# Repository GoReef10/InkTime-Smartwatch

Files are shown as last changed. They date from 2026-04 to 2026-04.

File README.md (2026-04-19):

# InkTime Smartwatch Project

InkTime is an open source startup focused on developing an affordable and customizable smartwatch centered around the nRF52840 SoC and e-ink display technology. This repository contains the full hardware design, including the schematic, PCB layout, and mechanical integration files required for mass production.

## Component Block Diagram
Block Diagram

## Bill of Materials

| Device | Value | Qty | Parts | Product Link | Datasheet Link |
| --- | --- | --: | --- | --- | --- |
| NORDIC_NRF_4_NRF52840_QF | nRF52840-QIAA | 1 | U1 | [JLCPCB](https://jlcpcb.com/partdetail/NordicSemicon-NRF52840_QIAAR/C190794) | [Datasheet](https://infocenter.nordicsemi.com/pdf/nRF52840_PS_v1.9.pdf) |
| RT6160AWSC | RT6160AWSC | 1 | IC9 | [JLCPCB](https://jlcpcb.com/partdetail/RichtekTech-RT6160AWSC/C7065276) | [Datasheet](https://www.mouser.com/datasheet/2/1458/DS6160A_03-3104604.pdf) |
| BQ25180YBGR | BQ25180YBGR | 1 | IC1 | [JLCPCB](https://jlcpcb.com/partdetail/TexasInstruments-BQ25180YBGR/C3682423) | [Datasheet](https://www.ti.com/lit/ds/symlink/bq25180.pdf) |
| ESP32_C6_LIBRARY_MAX17048G+T10 | MAX17048G+T10 | 1 | U3 | [JLCPCB](https://jlcpcb.com/partdetail/MaximIntegrated-MAX17048GT10/C2682616) | [Datasheet](https://www.analog.com/media/en/technical-documentation/data-sheets/MAX17048-MAX17049.pdf) |
| DRV2605YZFR | DRV2605YZFR | 1 | IC2 | [JLCPCB](https://jlcpcb.com/partdetail/TexasInstruments-DRV2605YZFR/C81079) | [Datasheet](https://www.ti.com/lit/ds/symlink/drv2605.pdf) |
| BMA421 | BMA421 | 1 | IC3 | [JLCPCB](https://jlcpcb.com/partdetail/BoschSensortec-BMA421/C5242966) | [Datasheet](https://files.pine64.org/doc/datasheet/pinetime/BST-BMA421-FL000.pdf) |
| DMG2305UX-7 | DMG2305UX-7 | 1 | Q2 | [JLCPCB](https://jlcpcb.com/partdetail/HXYMOSFET-DMG2305UX7/C5261054) | [Datasheet](https://www.diodes.com/assets/Datasheets/DMG2305UX.pdf) |
| ESP32_C6_LIBRARY_6_SI1308EDL-T1-GE3 | SI1308EDL-T1-GE3 | 1 | Q3 | [JLCPCB](https://jlcpcb.com/partdetail/TECHPUBLIC-SI1308EDL/C7603347) | [Datasheet](https://www.vishay.com/docs/63399/si1308edl.pdf) |
| USBLC6-2SC6Y | USBLC6-2SC6Y | 1 | D3 | [JLCPCB](https://jlcpcb.com/partdetail/TECHPUBLIC-USBLC62SC6Y/C5310974) | [Datasheet](https://wmsc.lcsc.com/wmsc/upload/file/pdf/v2/lcsc/2401261525_TECH-PUBLIC-USBLC6-2SC6Y_C5310974.pdf) |
| MBR0530 | MBR0530 | 3 | D2, D4, D5 | [JLCPCB](https://jlcpcb.com/partdetail/4324765-MBR0530_F20000HF/C3757235) | [Datasheet](https://wmsc.lcsc.com/wmsc/upload/file/pdf/v2/lcsc/2205311800_Yangzhou-Yangjie-Electronic-Technology-MBR0530-F2-0000HF_C3757235.pdf) |
| KH-TYPE-C-16P_KH-TYPE-C-16P | KH-TYPE-C-16P | 1 | J4 | [JLCPCB](https://jlcpcb.com/partdetail/KH-TYPE-C-16P/C709357) | [Datasheet](https://wmsc.lcsc.com/wmsc/upload/file/pdf/v2/lcsc/2204251630_SHENZHEN-KINGHELM-Elec-KH-TYPE-C-16P_C709357.pdf) |
| 5034802400 | 503480-2400 | 1 | J1 | [JLCPCB](https://jlcpcb.com/partdetail/MOLEX-5034802400/C122434) | [Datasheet](https://www.mouser.com/datasheet/2/276/2/5034802400_FFC_FPC_CONNECTORS-1112921.pdf) |
| EVP-AKE31A | EVP-AKE31A | 3 | SW_DN, SW_ENT, SW_UP | [JLCPCB](https://jlcpcb.com/partdetail/PANASONIC-EVPAKE31A/C569760) | [Datasheet](https://www.lcsc.com/datasheet/C569760.pdf) |
| 2450AT18B100E_2450AT18B100E | 2450AT18B100E | 1 | ANT1 | [JLCPCB](https://jlcpcb.com/partdetail/JohansonTechnology-2450AT18B100/C2836414) | [Datasheet](https://www.johansontechnology.com/datasheets/antennas/2450AT18B100.pdf) |
| NX2016SA-32MHZ-STD-CZS-5 | 32 MHz | 1 | X1 | [JLCPCB](https://jlcpcb.com/partdetail/NDK-NX2016SA_32MHZ_STD_CZS5/C843260) | [Datasheet](https://www.lcsc.com/datasheet/C843260.pdf) |
| NORDIC_NRF_1_XTAL_32KHZ | 32.768 kHz | 1 | X2 | [JLCPCB](https://jlcpcb.com/partdetail/NDK-NX3215SA_32_768K_STD_MUA9/C519280) | [Datasheet](https://www.ndk.com/images/products/crystal/resonator/NX3215SA_e.pdf) |
| MLP2016SR47MT0S1_FTC252012SR47MBCA | FTC252012SR47MBCA | 1 | L7 | [JLCPCB](https://jlcpcb.com/partdetail/6763488-FTC252012SR47MBCA/C5832368) | [Datasheet](https://wmsc.lcsc.com/wmsc/upload/file/pdf/v2/lcsc/2311271530_TDK-FTC252012SR47MBCA_C5832368.pdf) |
| VHF060303H3N9ST | 3.9 nH | 1 | L1 | [JLCPCB](https://jlcpcb.com/partdetail/153834-VHF060303H3N9ST/C142503) | [Datasheet](https://www.lcsc.com/datasheet/C142503.pdf) |
| MLK0603L15NJT000 | 15 nH | 1 | L3 | [JLCPCB](https://jlcpcb.com/partdetail/TDK-MLK0603L15NJT000/C6990407) | [Datasheet](https://www.lcsc.com/datasheet/C6990407.pdf) |
| RNCF0201DTC3K30 | 3.3 kΩ | 2 | R17, R18 | [JLCPCB](https://jlcpcb.com/partdetail/SEI_Stackpole_Elec-RNCF0201DTC3K30/C2487997) | [Datasheet](https://www.lcsc.com/datasheet/C2487997.pdf) |
| RC0201FR-075K1L | 5.1 kΩ | 2 | R1_USB, R2_USB | [JLCPCB](https://jlcpcb.com/partdetail/YAGEO-RC0201FR075K1L/C274341) | [Datasheet](https://www.lcsc.com/datasheet/C274341.pdf) |
| RC0201FR-1310KL | 10 kΩ | 6 | R2_EP_DR, R5, R7, R8, R9, R_PWR_EPD | [JLCPCB](https://jlcpcb.com/partdetail/YAGEO-RC0201FR1310KL/C6373588) | [Datasheet](https://www.lcsc.com/datasheet/C6373588.pdf) |
| 0201WMF220KTCE | 2.2 Ω | 1 | R_TYPE_SEL | [JLCPCB](https://jlcpcb.com/partdetail/244650-0201WMF220KTCE/C247442) | [Datasheet](https://www.lcsc.com/datasheet/C247442.pdf) |
| 0201WMJ0000TCE | 0 Ω | 3 | R2, R3, R4 | [JLCPCB](https://jlcpcb.com/partdetail/25793-0201WMJ0000TCE/C25050) | [Datasheet](https://www.lcsc.com/datasheet/C25050.pdf) |
| MA0201XF821K250 | 820 pF | 1 | C9 | [JLCPCB](https://jlcpcb.com/partdetail/Meritek-MA0201XF821K250/C3842403) | [Datasheet](https://www.lcsc.com/datasheet/C3842403.pdf) |
| GRM0335C1E1R0CA01J | 1 pF | 2 | C3, C4 | [JLCPCB](https://jlcpcb.com/partdetail/2274979-GRM0335C1E1R0CA01J/C2182912) | [Datasheet](https://www.lcsc.com/datasheet/C2182912.pdf) |
| 0201N120J250CT | 12 pF | 4 | C1, C2, C17, C18 | [JLCPCB](https://jlcpcb.com/partdetail/Walsin_TechCorp-0201N120J250CT/C424835) | [Datasheet](https://www.lcsc.com/datasheet/C424835.pdf) |
| 0201N101F160CT | 100 pF | 1 | C11 | [JLCPCB](https://jlcpcb.com/partdetail/Walsin_TechCorp-0201N101F160CT/C3847857) | [Datasheet](https://www.lcsc.com/datasheet/C3847857.pdf) |
| C0201X5R473K160NTA | 47 nF | 1 | C16 | [JLCPCB](https://jlcpcb.com/partdetail/126083-C0201X5R473K160NTA/C124806) | [Datasheet](https://www.lcsc.com/datasheet/C124806.pdf) |
| AC0201KRX6S6BB104 | 100 nF | 9 | C5, C7, C8, C12, C19, C23, C27, C34, C42 | [JLCPCB](https://jlcpcb.com/partdetail/YAGEO-AC0201KRX6S6BB104/C3855913) | [Datasheet](https://www.lcsc.com/datasheet/C3855913.pdf) |
| CL05A105KP5NNNC | 1 uF | 1 | C15 | [JLCPCB](https://jlcpcb.com/partdetail/C14445) | [Datasheet](https://www.lcsc.com/datasheet/C14445.pdf) |
| GRM155R61H105KE05D | 1 uF / 50V | 9 | EPD_C1, EPD_C2, EPD_C6, EPD_C7, EPD_C8, EPD_C9, EPD_C10, EPD_C11, EPD_C12 | [JLCPCB](https://jlcpcb.com/partdetail/1609005-GRM155R61H105KE05D/C1518208) | [Datasheet](https://www.lcsc.com/datasheet/C1518208.pdf) |
| GRM155R61A475KEAAD | 4.7 uF | 5 | C6, C14, C20, C21, C43 | [JLCPCB](https://jlcpcb.com/partdetail/MurataElectronics-GRM155R61A475KEAAD/C77004) | [Datasheet](https://www.lcsc.com/datasheet/C77004.pdf) |
| C0402X5R475M250NT | 4.7 uF / 25V | 1 | C2-EP-DR | [JLCPCB](https://jlcpcb.com/partdetail/SANYEAR-C0402X5R475M250NT/C2911388) | [Datasheet](https://www.lcsc.com/datasheet/C2911388.pdf) |
| 0402X106M100CT | 10 uF | 2 | C24, C39 | [JLCPCB](https://jlcpcb.com/partdetail/Walsin_TechCorp-0402X106M100CT/C2992625) | [Datasheet](https://www.lcsc.com/datasheet/C2992625.pdf) |
| CL05A226MQ6ZUN8 | 22 uF | 2 | C25, C33 | [JLCPCB](https://jlcpcb.com/partdetail/2889851-CL05A226MQ6ZUN8/C2762589) | [Datasheet](https://www.lcsc.com/datasheet/C2762589.pdf) |

## Hardware Description

### Microcontroller - nRF52840 (Nordic Semiconductor)

The core of InkTime is the **nRF52840**. It manages all peripherals and runs the main firmware:

### Power System

- **LiPo Charger - BQ25180YBGR :** Single-cell Li-Ion/LiPo charger connected via **I2C**, handles charge current control and power path management.
- **DC/DC Buck-Boost - RT6160AWSC:** Provides the regulated **3.3 V rail** (VREG/3V3) from the battery, using a 10 uH inductor. Supplies the MCU and most peripherals.
- **Fuel Gauge - MAX17048G+T10:** Monitors battery state-of-charge via **I2C**, provides a `ALERT` line to the MCU for low-battery interrupts.

### E-Paper Display

The display connects through a 24-pin FPC connector (J1). The drive circuit uses:
- A boost converter to generate the higher voltages required by e-paper panels (PREVGH/PREVGL rails).
- Communication with the MCU via SPI (MOSI, SCK, CS, DC, RST, BUSY lines).

E-paper was chosen for its near-zero power draw when the display is static - only consuming power during refresh.

### IMU - BMA421

A 3-axis accelerometer connected via I2C, with two interrupt lines (`INT1`, `INT2`) wired to the MCU for step counting, wrist-tilt detection, and activity recognition without polling.

### Haptic Driver - DRV2605YZFR

Controls a vibration motor/LRA actuator. Connected via **I2C**, with an enable line (`HAPTIC_EN`) from the MCU. Supports waveform libraries for rich haptic feedback patterns.

### USB - KH-TYPE-C-16P + USBLC6-2SC6Y

Full-speed USB Type-C connector for charging and data. The USBLC6-2SC6Y provides ESD protection on D+/D− lines. CC1/CC2 resistors (5.1 kΩ) handle cable orientation detection. VBUS is routed to the LiPo charger.

### Buttons

Three tactile buttons (UP, DOWN, ENTER) with pull-up resistors, directly connected to GPIO pins.

### Debug Interface - TC2030-IDC (Tag-Connect)

A 6-pin **SWD** debug/programming header (SWDCLK, SWDIO, RESET, SWO, 3.3V, GND) for firmware flashing and debugging, with test points exposed for each signal.

## nRF52840 Pin Assignment - InkTime v5

### SPI - E-Paper Display
| Pin | Function | Why |
|-----|---|-----|
| P0.08 | MOSI | SPI data out to EPD controller |
| P0.11 | SCK | SPI clock |
| P0.13 | EPD_CS | Chip select - activates the display |
| P0.14 | EPD_DC | Data/Command toggle for EPD protocol |
| P1.01 | EPD_RST | Hardware reset of the display controller |
| P1.02 | EPD_BUSY | Polled input - MCU waits for display to finish refreshing |

### I2C - Shared Bus (BQ25180, MAX17048, BMA421, DRV2605)
| Pin | Function | Why |
|-----|---|-----|
| P0.26 | SCL | I2C clock, shared by all 4 peripherals |
| P0.27 | SDA | I2C data, shared by all 4 peripherals |

### Interrupts & Control
| Pin | Function | Why |
|-----|---|-----|
| P0.04 | PMIC_INT | BQ25180 interrupt - charge events (fault, complete, etc.) |
| P1.09 | ALERT | MAX17048 interrupt - low battery or 1% SoC change |
| P0.25 | IMU_INT1 | BMA421 primary interrupt - step count, wakeup-on-motion |
| P0.24 | IMU_INT2 | BMA421 secondary interrupt - activity recognition events |
| P1.01 | HAPTIC_EN | Enables DRV2605 and triggers haptic waveform playback |

### Buttons
| Pin | Function | Why |
|-----|---|-----|
| P0.29 | SW_UP | Up button - GPIOTE falling-edge interrupt, also wakes MCU from sleep |
| P0.30 | SW_DN | Down button - same as above |
| P0.31 | SW_ENT | Enter button - same as above |

### USB
| Pin | Function | Why |
|-----|---|-----|
| D+ | USB D+ | Native USB 2.0 FS controller - firmware updates, serial debug |
| D− | USB D− | Paired with D+ |
| VBUS | USB power detect | MCU detects cable insertion to enable charging path |

### Crystal Oscillators
| Pin | Function | Why |
|-----|---|-----|
| XL1 / XL2 | 32.768 kHz XTAL | Low-frequency RTC clock - timekeeping during deep sleep |
| XC1 / XC2 | 32 MHz XTAL | Main system clock for CPU and radio |

### SWD Debug
| Pin | Function | Why |
|-----|---|-----|
| SWDCLK | SWD clock | Firmware flashing and live debugging via Tag-Connect |
| SWDIO | SWD data | Bidirectional debug data |
| P1.00 | SWO | Serial Wire Output - trace/printf during development |
| P0.18 | RESET | Hardware reset, also accessible on debug header |

### RF
| Pin | Function | Why |
|-----|---|-----|
| ANT | 2.4 GHz antenna | Connected via LC matching network to the onboard ceramic antenna |
| VSS_PA | PA ground | Dedicated quiet ground for the RF power amplifier |

## Design Log

### Silkscreen
Silkscreen line width was set to **0.9 mm**, reduced to **0.8 mm** in areas where overlap with component courtyard or pad holes would otherwise occur. While the standard recommendation is 1 mm, 0.9 mm remains legible after fabrication. To reduce visual clutter, silkscreen labels were kept only for functionally important components (ICs, connectors, test points) - passive components such as resistors and capacitors were left unlabeled.

### Test Points
All test points (SWD signals, power rails, I2C lines) were placed close to the board edge to allow easy probing during bring-up and testing without needing to reach into the center of the board.

### Antenna Placement
The BLE antenna (2450AT18B100E) was placed at the edge of the PCB, away from other components and copper fills, to minimize RF interference and avoid detuning the antenna due to nearby conductors - a standard requirement for 2.4 GHz PCB antennas.

### Trace Width & Clearance
Power traces were routed at 0.3 mm as per design requirements. In a small number of cases, traces were temporarily narrowed immediately at component pins due to clearance constraints, then returned to 0.3 mm as soon as space allowed. This was done only where unavoidable and over very short distances, keeping the resistive impact negligible.

### 2-Layer Stackup
A 2-layer board (top + bottom copper) was chosen deliberately as the design complexity is manageable within 2 layers, so the added cost of additional layers would bring no practical benefit.

Power traces were routed on the top layer. The only exception is a short segment of the **3V3 trace** which briefly routes through the bottom layer through 3 vias, due to a localized routing constraint. This was kept to an absolute minimum, which is particularly important for noisy nets like the e-paper boost converter output.

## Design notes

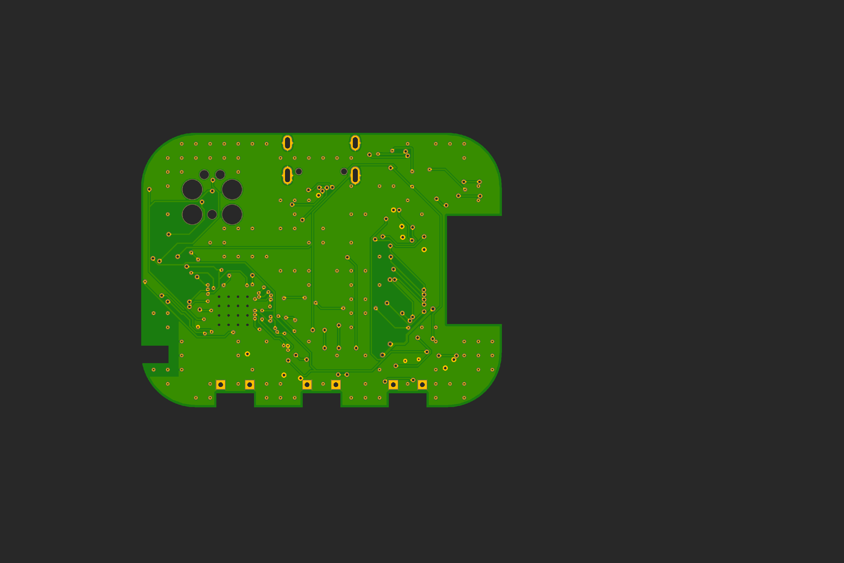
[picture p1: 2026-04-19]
Images/PCB Bottom.png

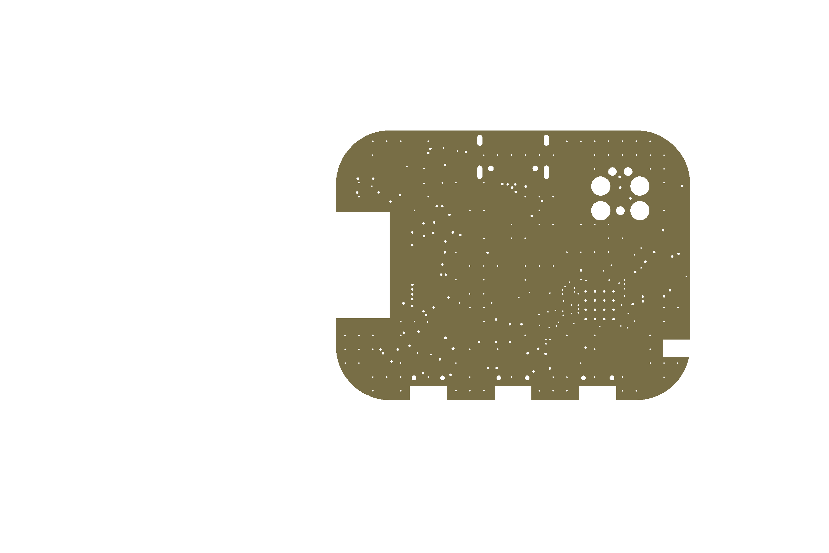
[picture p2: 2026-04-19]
Images/PCB Drills.png

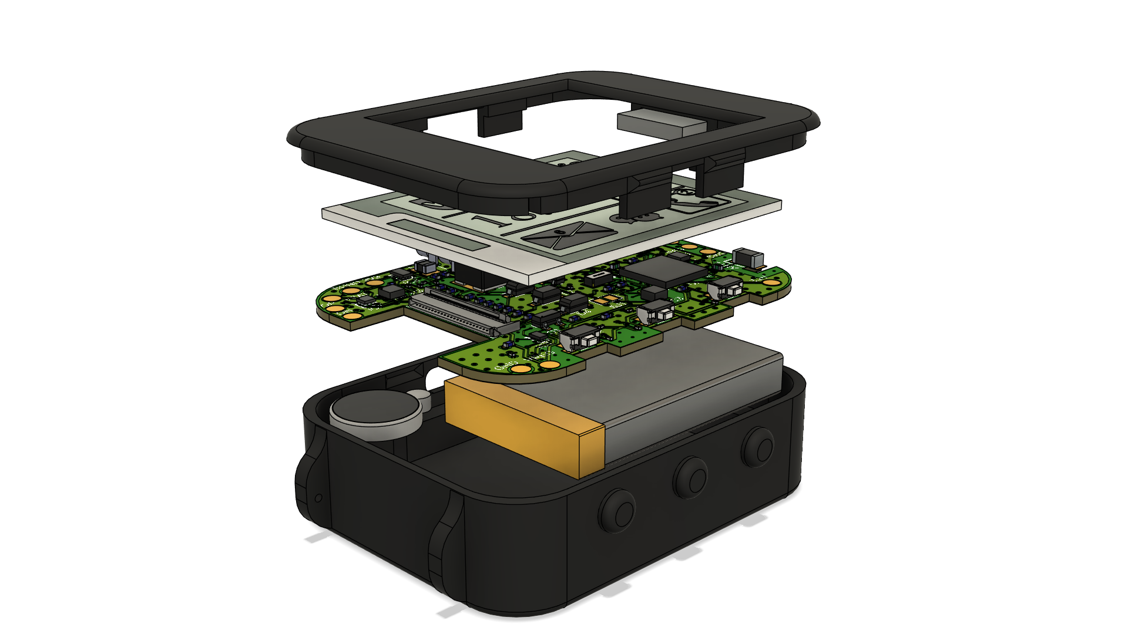
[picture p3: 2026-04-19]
Images/Exploded View.png

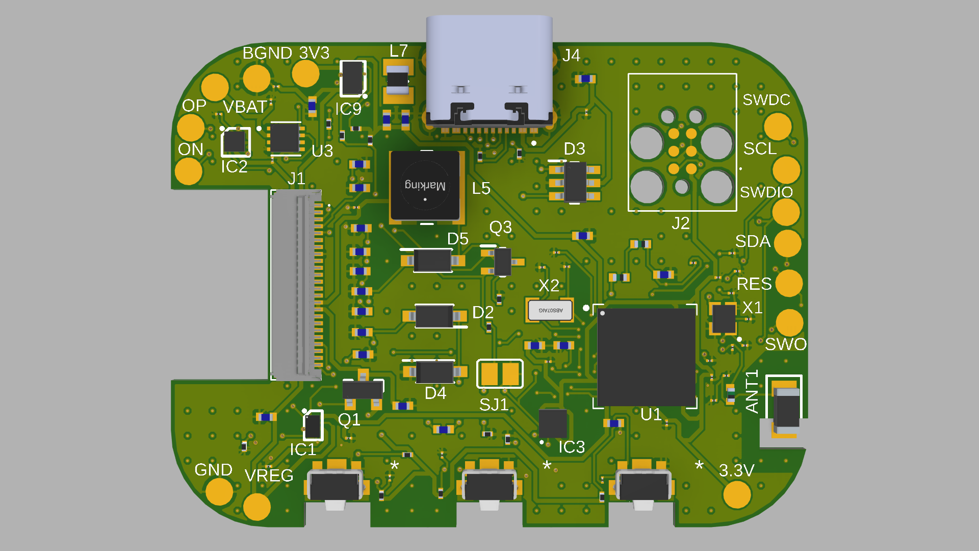
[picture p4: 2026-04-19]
Images/PCB Top View Render.png

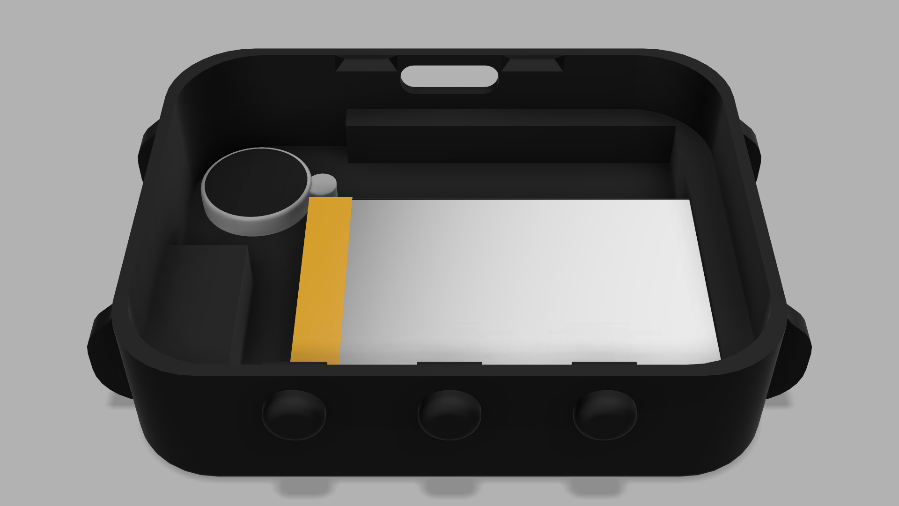
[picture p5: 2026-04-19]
Images/Inside Case.png

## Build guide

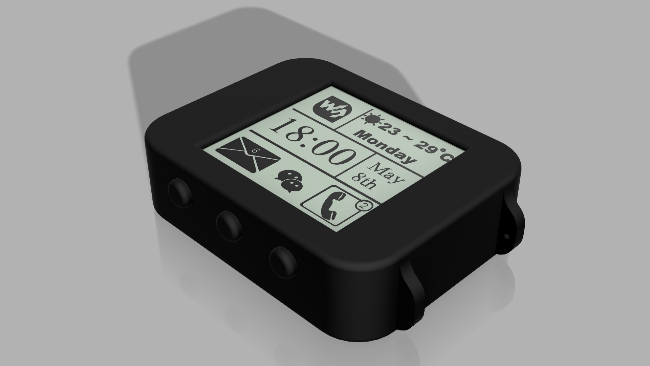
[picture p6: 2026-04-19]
Images/Assembled.png

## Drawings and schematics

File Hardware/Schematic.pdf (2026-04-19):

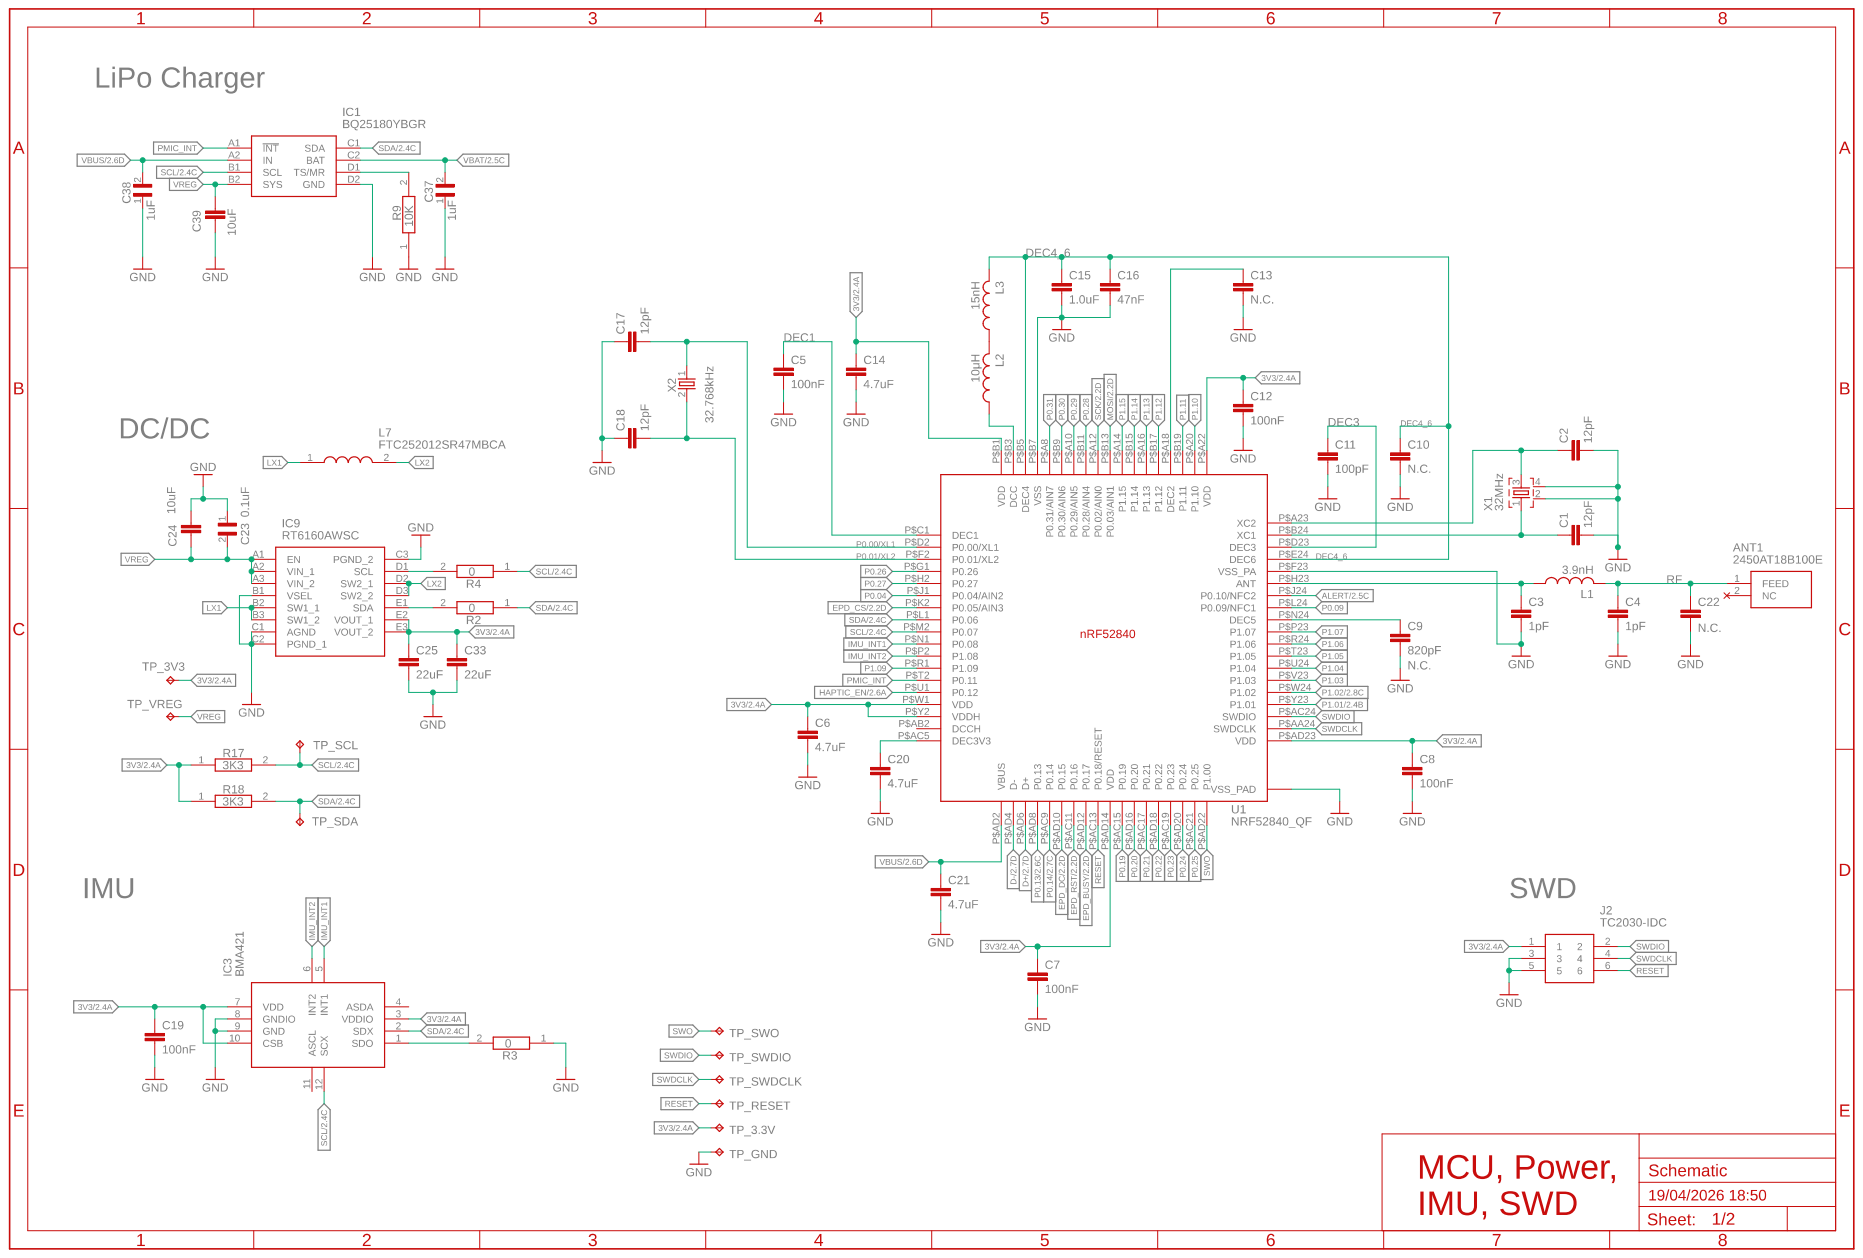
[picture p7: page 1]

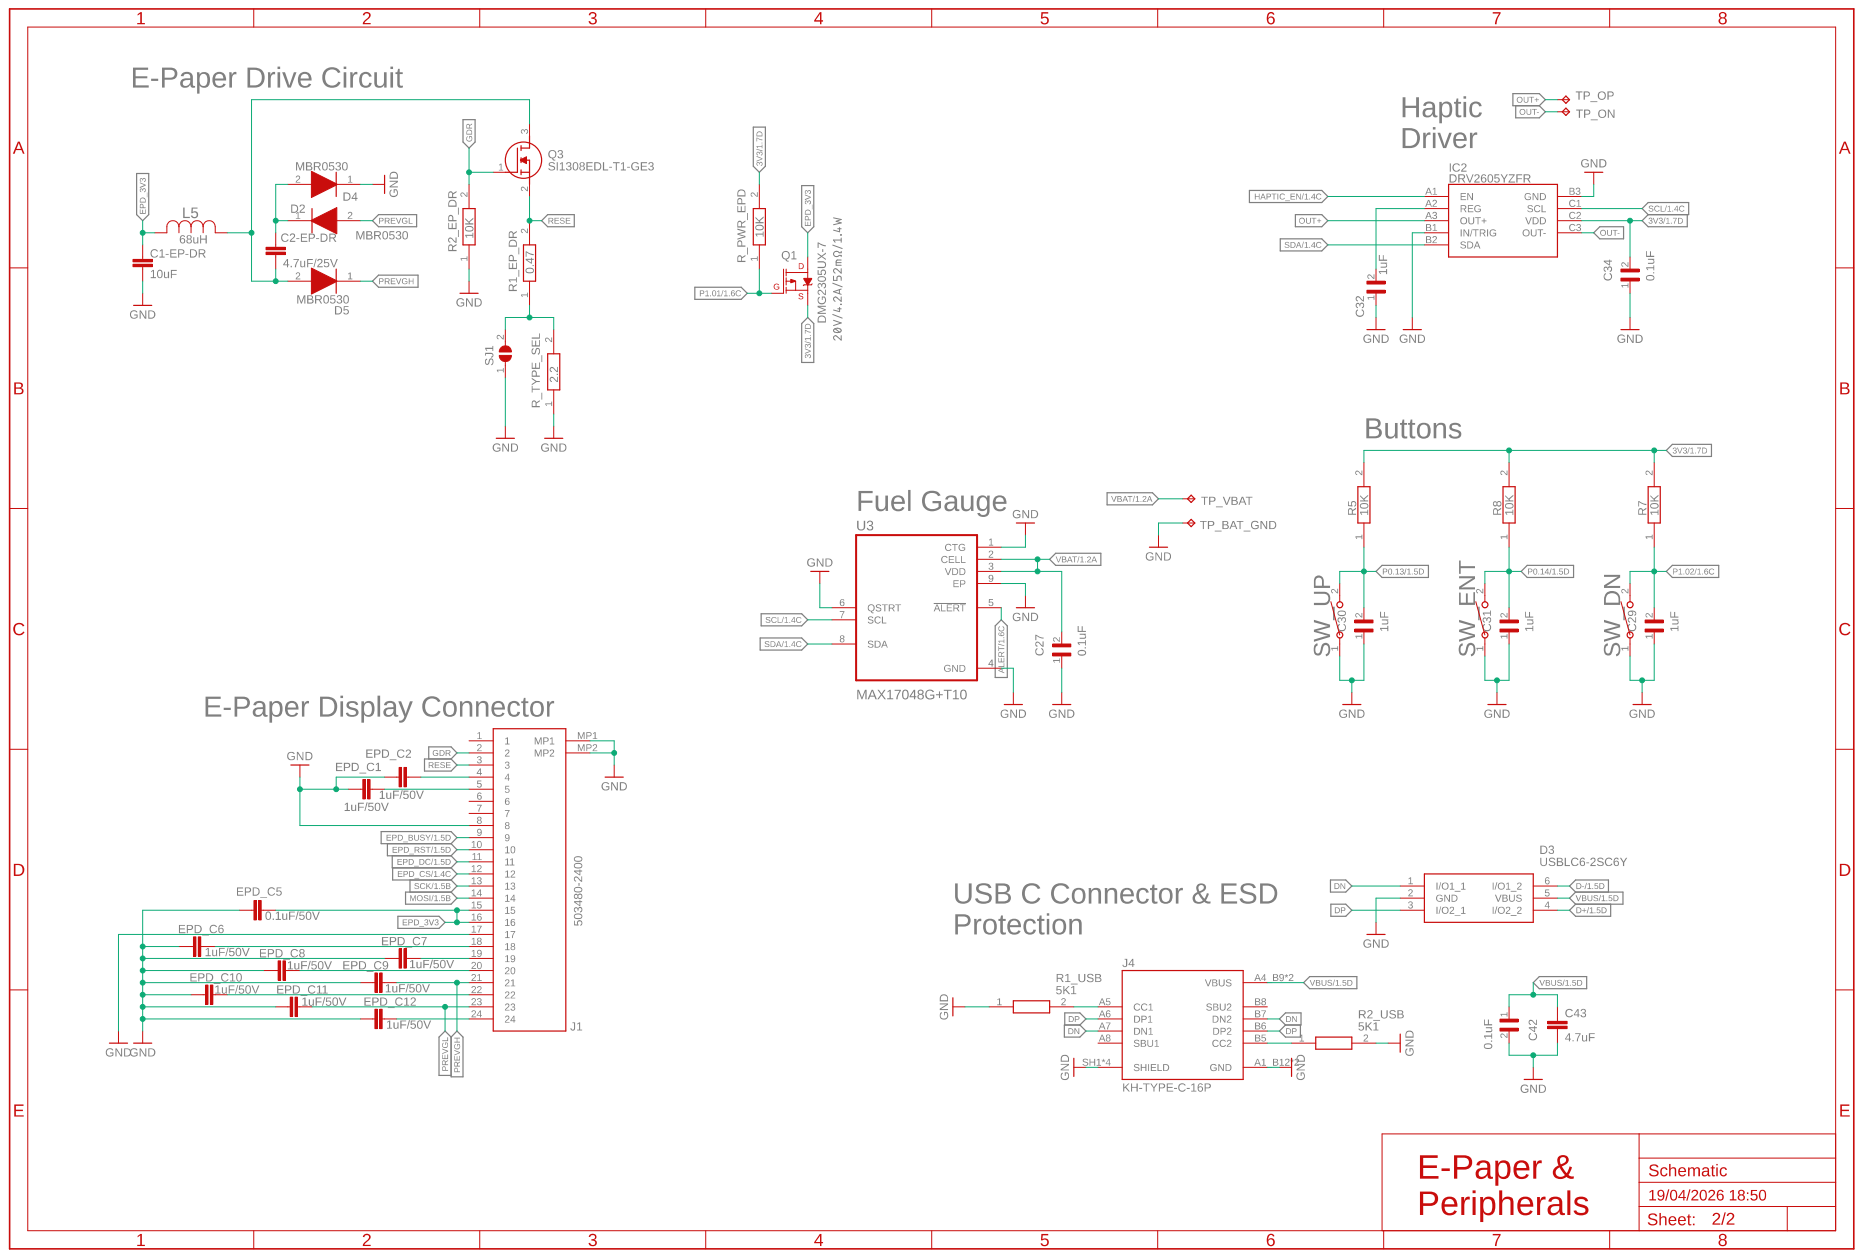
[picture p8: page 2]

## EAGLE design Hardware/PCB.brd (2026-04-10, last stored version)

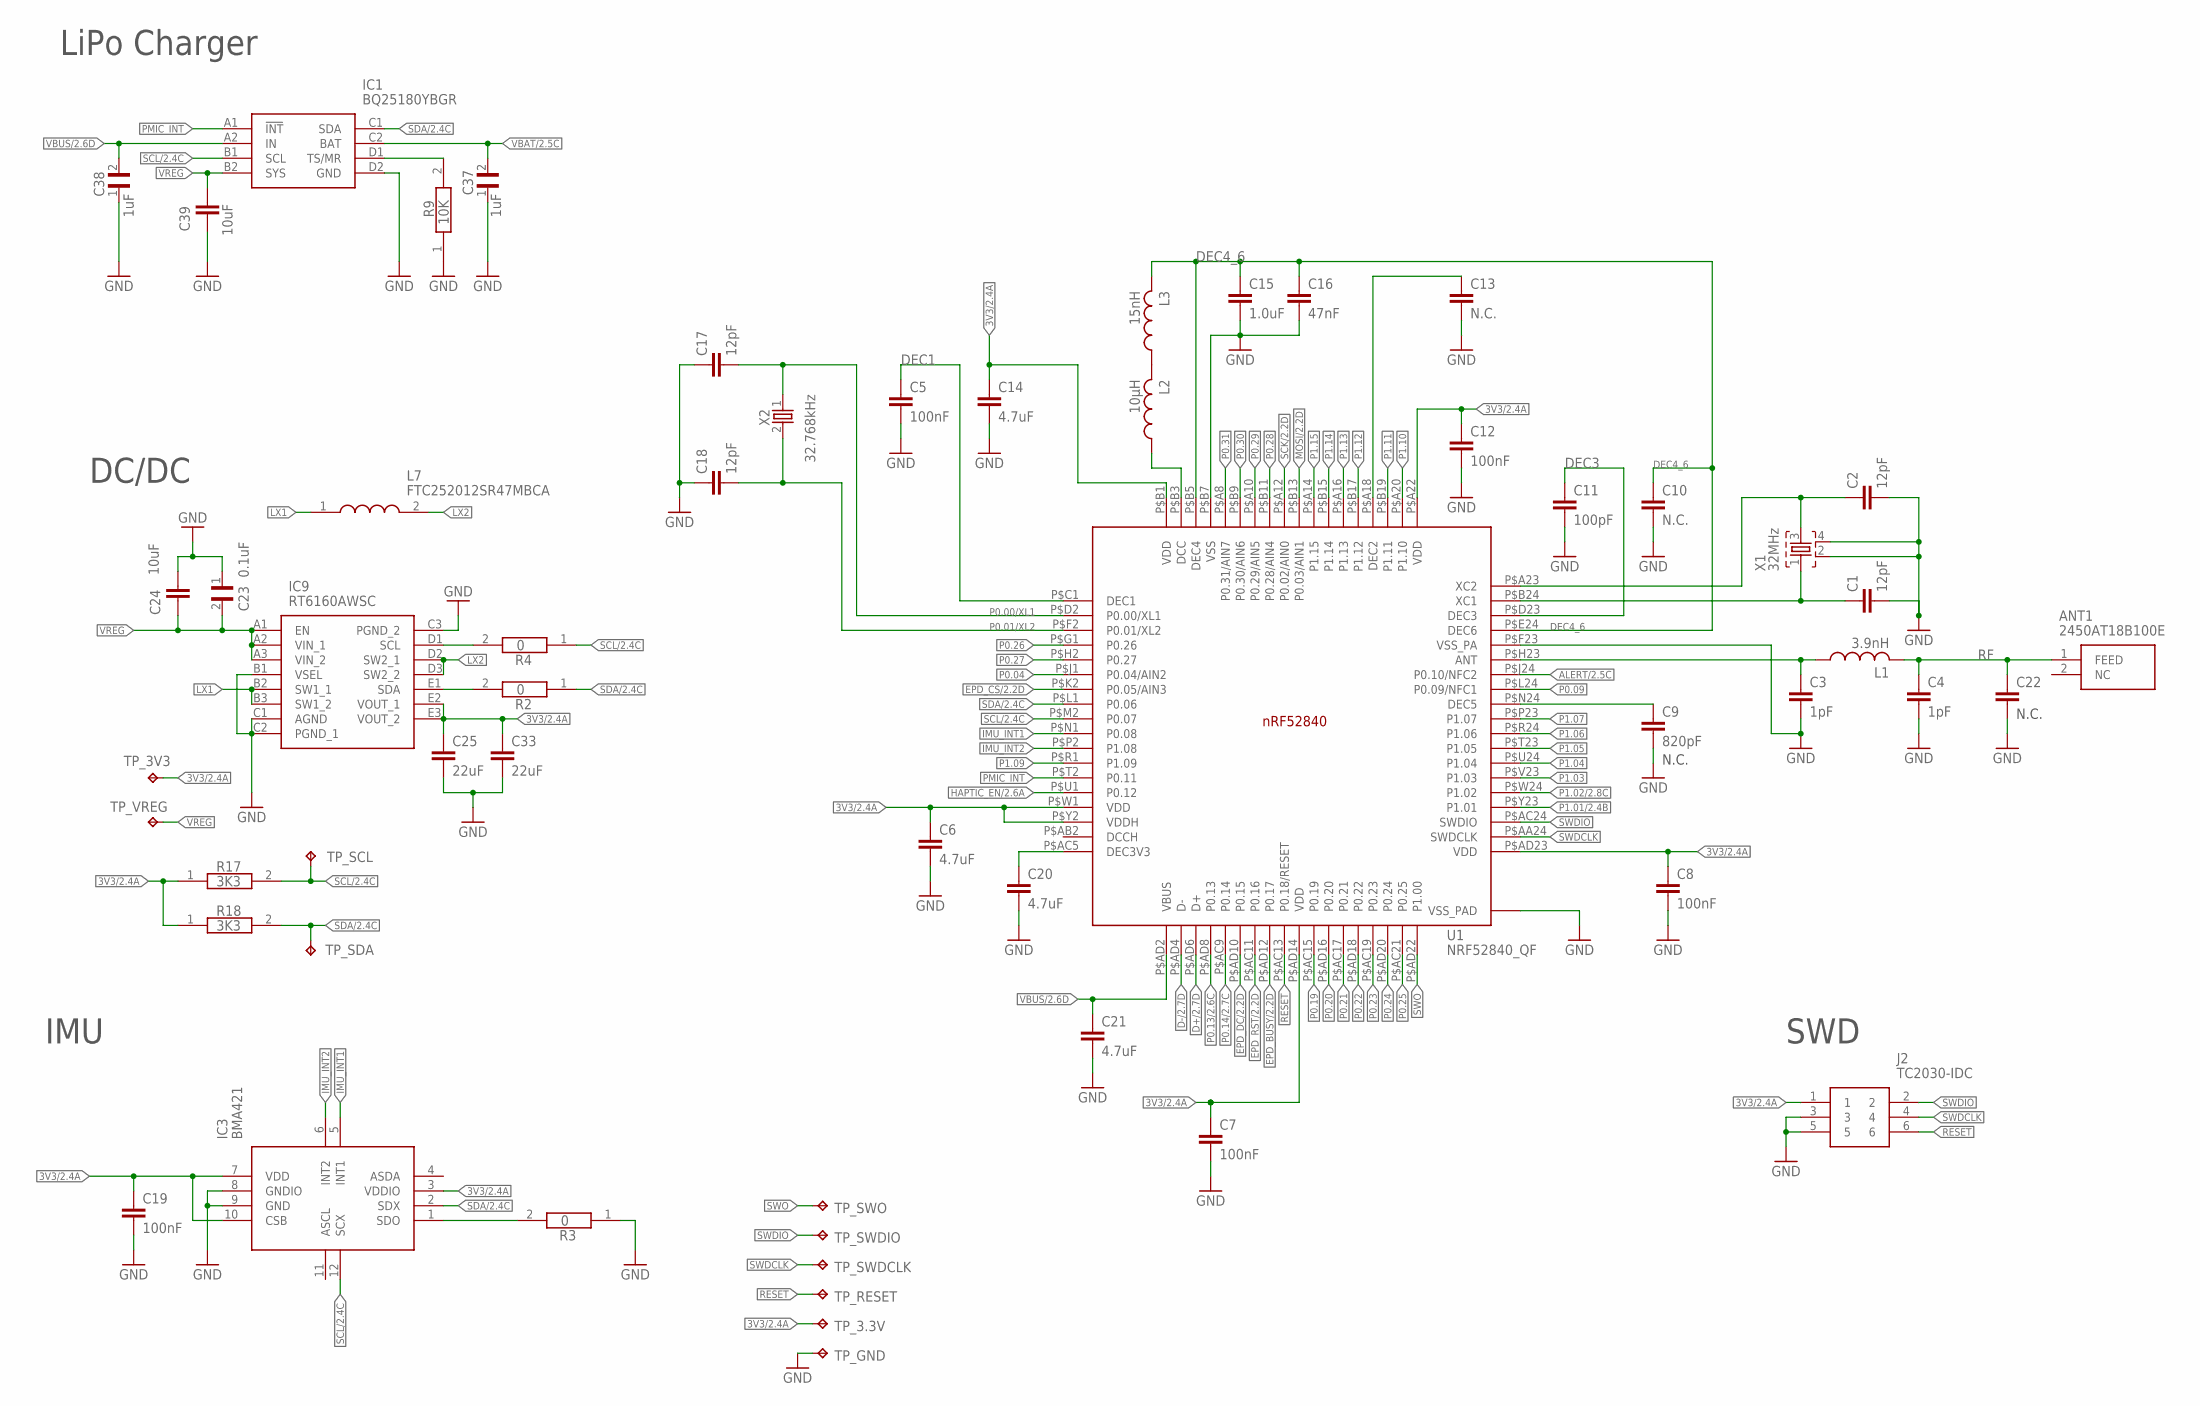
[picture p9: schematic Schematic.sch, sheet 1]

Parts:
ANT1: 2450AT18B100E; 2450AT18B100E_ANTC3216X140N
C1, C2, C17, C18: 12pF; NORDIC_NRF_3_RESC0201_L
C3, C4: 1pF; NORDIC_NRF_3_RESC0201_L
C5, C7, C8, C12, C19: 100nF; NORDIC_NRF_3_RESC0201_L
C6, C14, C20, C21: 4.7uF; NORDIC_NRF_3_RESC0402_L
C9: 820pF; NORDIC_NRF_3_RESC0201_L
C10, C13, C22: N.C.; NORDIC_NRF_3_RESC0201_L
C11: 100pF; NORDIC_NRF_3_RESC0201_L
C15: 1.0uF; NORDIC_NRF_3_RESC0402_L
C16: 47nF; NORDIC_NRF_3_RESC0201_L
C23: 0.1uF; GRM011R60J152KE01L_1_0201
C24, C39: 10uF; NORDIC_NRF_3_RESC0402_L
C25, C33: 22uF; NORDIC_NRF_3_RESC0402_L
C37, C38: 1uF; GRM011R60J152KE01L_1_0201
IC1: BQ25180YBGR; BQ25180YBGR_BGA8C40P2X4_100X155X50
IC3: BMA421; BMA423_BMA423
IC9: RT6160AWSC; RT6160AWSC_BGA15C40P3X5_140X230X60
J2: TC2030-IDC; TC2030-IDC_TC2030IDC
L1: 3.9nH; NORDIC_NRF_2_RESC0402_L
L2: 10μH; NORDIC_NRF_2_RESC0402_L
L3: 15nH; NORDIC_NRF_2_RESC0402_L
L7: FTC252012SR47MBCA; MLP2016SR47MT0S1_INDC2016X100N
R2, R3, R4: 0; ERA-1AEB3401C_0201
R9: 10K; ERA-1AEB3401C_0201
R17, R18: 3K3; ERA-1AEB3401C_0201
TP_3.3V, TP_3V3: HECTOR_WATCH_1_TPTP20R; HECTOR_WATCH_1_TP20R
TP_GND: HECTOR_WATCH_1_TPTP20R; HECTOR_WATCH_1_TP20R
TP_RESET: HECTOR_WATCH_1_TPTP20R; HECTOR_WATCH_1_TP20R
TP_SCL: HECTOR_WATCH_1_TPTP20R; HECTOR_WATCH_1_TP20R
TP_SDA: HECTOR_WATCH_1_TPTP20R; HECTOR_WATCH_1_TP20R
TP_SWDCLK: HECTOR_WATCH_1_TPTP20R; HECTOR_WATCH_1_TP20R
TP_SWDIO: HECTOR_WATCH_1_TPTP20R; HECTOR_WATCH_1_TP20R
TP_SWO: HECTOR_WATCH_1_TPTP20R; HECTOR_WATCH_1_TP20R
TP_VREG: HECTOR_WATCH_1_TPTP20R; HECTOR_WATCH_1_TP20R
U1: NRF52840_QF; NORDIC_NRF_4_AQFN50P700X700X85_HS-74N
X1: 32MHz; NORDIC_NRF_BT-XTAL_2016_N
X2: 32.768kHz; NORDIC_NRF_1_XTAL_3215_N

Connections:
3V3/2.4A: C6.1, C7.1, C8.1, C12.1, C14.1, C19.1, C25.1, C33.1, IC3.3 (VDDIO), IC3.7 (VDD), IC3.10 (CSB), IC9.E2 (VOUT_1), IC9.E3 (VOUT_2), J2.1, R17.1, R18.1, TP_3.3V.TP, TP_3V3.TP, U1.P$A22 (VDD), U1.P$AD14 (VDD), U1.P$AD23 (VDD), U1.P$B1 (VDD), U1.P$W1 (VDD), U1.P$Y2 (VDDH)
ALERT/2.5C: U1.P$J24 (P0.10/NFC2)
D+/2.7D: U1.P$AD6 (D+)
D-/2.7D: U1.P$AD4 (D-)
DEC1: C5.1, U1.P$C1 (DEC1)
DEC3: C11.1, U1.P$D23 (DEC3)
DEC4_6: C10.1, C15.1, C16.1, L3.2, U1.P$B5 (DEC4), U1.P$E24 (DEC6)
EPD_BUSY/2.2D: U1.P$AD12 (P0.17)
EPD_CS/2.2D: U1.P$K2 (P0.05/AIN3)
EPD_DC/2.2D: U1.P$AD10 (P0.15)
EPD_RST/2.2D: U1.P$AC11 (P0.16)
GND: C1.2, C2.2, C3.2, C4.2, C5.2, C6.2, C7.2, C8.2, C9.2, C10.2, C11.2, C12.2, C13.2, C14.2, C15.2, C16.2, C17.1, C18.1, C19.2, C20.2, C21.2, C22.2, C23.1, C24.1, C25.2, C33.2, C37.1, C38.1, C39.2, IC1.D2 (GND), IC3.8 (GNDIO), IC3.9 (GND), IC9.B1 (VSEL), IC9.C1 (AGND), IC9.C2 (PGND_1), IC9.C3 (PGND_2), J2.3, J2.5, R3.1, R9.1, TP_GND.TP, U1.P$74 (VSS_PAD), U1.P$75 (VSS_PAD), U1.P$76 (VSS_PAD), U1.P$77 (VSS_PAD), U1.P$78 (VSS_PAD), U1.P$79 (VSS_PAD), U1.P$80 (VSS_PAD), U1.P$81 (VSS_PAD), U1.P$82 (VSS_PAD), U1.P$83 (VSS_PAD), U1.P$84 (VSS_PAD), U1.P$85 (VSS_PAD), U1.P$86 (VSS_PAD), U1.P$87 (VSS_PAD), U1.P$88 (VSS_PAD), U1.P$89 (VSS_PAD), U1.P$90 (VSS_PAD), U1.P$B7 (VSS), U1.P$F23 (VSS_PA), X1.2, X1.4; also elsewhere on the board
HAPTIC_EN/2.6A: U1.P$U1 (P0.12)
IMU_INT1: IC3.5 (INT1), U1.P$N1 (P0.08)
IMU_INT2: IC3.6 (INT2), U1.P$P2 (P1.08)
LX1: IC9.B2 (SW1_1), IC9.B3 (SW1_2), L7.1
LX2: IC9.D2 (SW2_1), IC9.D3 (SW2_2), L7.2
MOSI/2.2D: U1.P$B13 (P0.03/AIN1)
unnamed: C20.1, U1.P$AC5 (DEC3V3)
unnamed: L2.2, L3.1
unnamed: L2.1, U1.P$B3 (DCC)
unnamed: C1.1, U1.P$B24 (XC1), X1.1
unnamed: C2.1, U1.P$A23 (XC2), X1.3
unnamed: IC9.E1 (SDA), R2.2
unnamed: IC9.D1 (SCL), R4.2
unnamed: IC1.D1 (TS/MR), R9.2
unnamed: C13.1, U1.P$A18 (DEC2)
unnamed: C9.1, U1.P$N24 (DEC5)
unnamed: IC3.1 (SDO), R3.2
unnamed: C3.1, L1.1, U1.P$H23 (ANT)
P0.00/XL1: C17.2, U1.P$D2 (P0.00/XL1), X2.1
P0.01/XL2: C18.2, U1.P$F2 (P0.01/XL2), X2.2
P0.04: U1.P$J1 (P0.04/AIN2)
P0.09: U1.P$L24 (P0.09/NFC1)
P0.13/2.6C: U1.P$AD8 (P0.13)
P0.14/2.7C: U1.P$AC9 (P0.14)
P0.19: U1.P$AC15 (P0.19)
P0.20: U1.P$AD16 (P0.20)
P0.21: U1.P$AC17 (P0.21)
P0.22: U1.P$AD18 (P0.22)
P0.23: U1.P$AC19 (P0.23)
P0.24: U1.P$AD20 (P0.24)
P0.25: U1.P$AC21 (P0.25)
P0.26: U1.P$G1 (P0.26)
P0.27: U1.P$H2 (P0.27)
P0.28: U1.P$B11 (P0.28/AIN4)
P0.29: U1.P$A10 (P0.29/AIN5)
P0.30: U1.P$B9 (P0.30/AIN6)
P0.31: U1.P$A8 (P0.31/AIN7)
P1.01/2.4B: U1.P$Y23 (P1.01)
P1.02/2.8C: U1.P$W24 (P1.02)
P1.03: U1.P$V23 (P1.03)
P1.04: U1.P$U24 (P1.04)
P1.05: U1.P$T23 (P1.05)
P1.06: U1.P$R24 (P1.06)
P1.07: U1.P$P23 (P1.07)
P1.09: U1.P$R1 (P1.09)
P1.10: U1.P$A20 (P1.10)
P1.11: U1.P$B19 (P1.11)
P1.12: U1.P$B17 (P1.12)
P1.13: U1.P$A16 (P1.13)
P1.14: U1.P$B15 (P1.14)
P1.15: U1.P$A14 (P1.15)
PMIC_INT: IC1.A1 (!INT), U1.P$T2 (P0.11)
RESET: J2.6, TP_RESET.TP, U1.P$AC13 (P0.18/RESET)
RF: ANT1.1 (FEED), C4.1, C22.1, L1.2
SCK/2.2D: U1.P$A12 (P0.02/AIN0)
SCL/2.4C: IC1.B1 (SCL), IC3.12 (SCX), R4.1, R17.2, TP_SCL.TP, U1.P$M2 (P0.07)
SDA/2.4C: IC1.C1 (SDA), IC3.2 (SDX), R2.1, R18.2, TP_SDA.TP, U1.P$L1 (P0.06)
SWDCLK: J2.4, TP_SWDCLK.TP, U1.P$AA24 (SWDCLK)
SWDIO: J2.2, TP_SWDIO.TP, U1.P$AC24 (SWDIO)
SWO: TP_SWO.TP, U1.P$AD22 (P1.00)
VBAT/2.5C: C37.2, IC1.C2 (BAT)
VBUS/2.6D: C21.1, C38.2, IC1.A2 (IN), U1.P$AD2 (VBUS)
VREG: C23.2, C24.2, C39.1, IC1.B2 (SYS), IC9.A1 (EN), IC9.A2 (VIN_1), IC9.A3 (VIN_2), TP_VREG.TP

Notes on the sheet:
LiPo Charger
DC/DC
IMU
SWD
N.C.

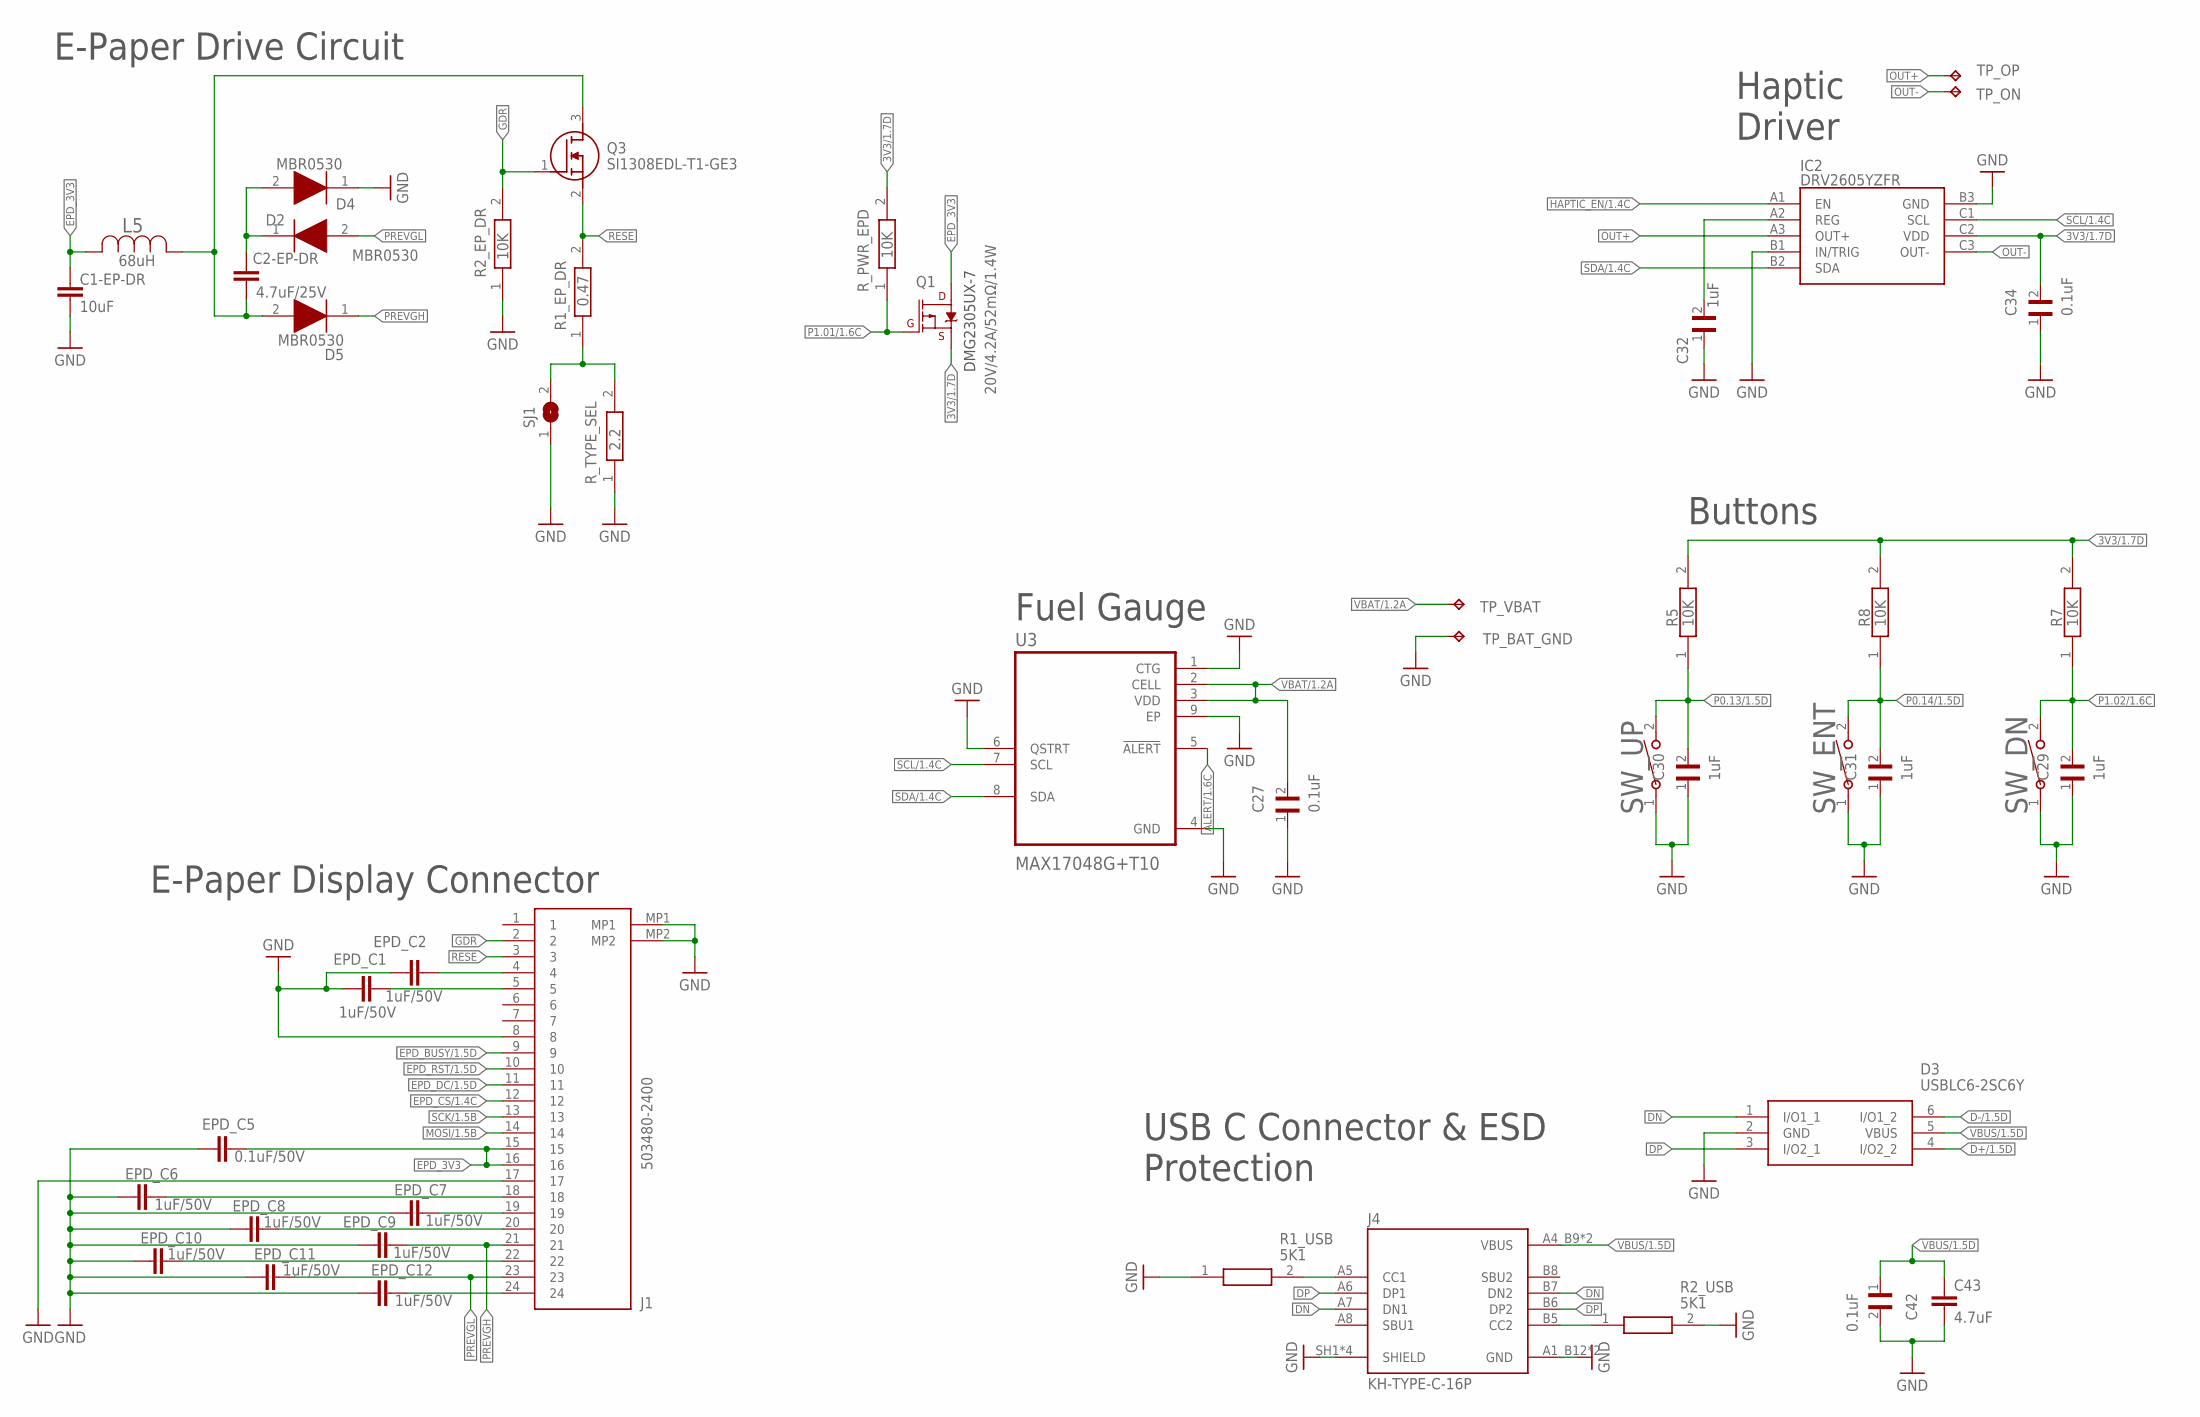
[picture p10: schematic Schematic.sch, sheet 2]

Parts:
C1-EP-DR: 10uF; NORDIC_NRF_3_RESC0402_L
C2-EP-DR: 4.7uF/25V; NORDIC_NRF_3_RESC0402_L
C27, C34, C42: 0.1uF; GRM011R60J152KE01L_1_0201
C29, C30, C31, C32: 1uF; GRM011R60J152KE01L_1_0201
C43: 4.7uF; NORDIC_NRF_3_RESC0402_L
D2, D4, D5: MBR0530; ESP32_C6_LIBRARY_5_SOD3716X135N
D3: USBLC6-2SC6Y; ESP32_C6_LIBRARY_3_SOT95P280X145-6N
EPD_C1, EPD_C2, EPD_C6, EPD_C7, EPD_C8, EPD_C9, EPD_C10, EPD_C11, EPD_C12: 1uF/50V; NORDIC_NRF_3_RESC0402_L
EPD_C5: 0.1uF/50V; NORDIC_NRF_3_RESC0201_L
IC2: DRV2605YZFR; DRV2605YZFR_BGA9C50P3X3_144X144X62
J1: 503480-2400; 503480-2400_5034802400
J4: KH-TYPE-C-16P; KH-TYPE-C-16P_KINGHELM_KH-TYPE-C-16P
L5: 68uH; ESP32_C6_LIBRARY_2_IND_4828-WE-TPC_WRE
Q1: 20V/4.2A/52mΩ/1.4W; ESP32_C6_LIBRARY_4_ESP32_C6_LIBRARY_4_ESP32_C6_LIBRARY_4_ES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
Q3: SI1308EDL-T1-GE3; ESP32_C6_LIBRARY_6_SOT65P210X110-3N
R1_EP_DR: 0.47; ERA-1AEB3401C_0201
R1_USB, R2_USB: 5K1; ERA-1AEB3401C_0201
R2_EP_DR, R5, R7, R8: 10K; ERA-1AEB3401C_0201
R_PWR_EPD: 10K; ERA-1AEB3401C_0201
R_TYPE_SEL: 2.2; ERA-1AEB3401C_0201
SJ1: ESP32_C6_LIBRARY_7_JUMPER_SJ
SW_DN: 2025-10-22_07-23-44_LIBRARY_EVP-AKE31ASW_EVP-AKE3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; 2025-10-22_07-23-44_LIBRARY_SW_EVP-AKE31A_PAN
SW_ENT: 2025-10-22_07-23-44_LIBRARY_EVP-AKE31ASW_EVP-AKE3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; 2025-10-22_07-23-44_LIBRARY_SW_EVP-AKE31A_PAN
SW_UP: 2025-10-22_07-23-44_LIBRARY_EVP-AKE31ASW_EVP-AKE3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; 2025-10-22_07-23-44_LIBRARY_SW_EVP-AKE31A_PAN
TP_BAT_GND: HECTOR_WATCH_1_TPTP20R; HECTOR_WATCH_1_TP20R
TP_ON: HECTOR_WATCH_1_TPTP20R; HECTOR_WATCH_1_TP20R
TP_OP: HECTOR_WATCH_1_TPTP20R; HECTOR_WATCH_1_TP20R
TP_VBAT: HECTOR_WATCH_1_TPTP20R; HECTOR_WATCH_1_TP20R
U3: MAX17048G+T10; ESP32_C6_LIBRARY_SON50P200X200X80-9N

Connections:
3V3/1.7D: C34.2, IC2.C2 (VDD), Q1.2 (S), R5.2, R7.2, R8.2, R_PWR_EPD.2
ALERT/1.6C: U3.5 (!ALERT)
D+/1.5D: D3.4 (I/O2_2)
D-/1.5D: D3.6 (I/O1_2)
DN: D3.1 (I/O1_1), J4.A7 (DN1), J4.B7 (DN2)
DP: D3.3 (I/O2_1), J4.A6 (DP1), J4.B6 (DP2)
EPD_3V3: C1-EP-DR.2, EPD_C5.2, J1.15, J1.16, L5.2, Q1.3 (D)
EPD_BUSY/1.5D: J1.9
EPD_CS/1.4C: J1.12
EPD_DC/1.5D: J1.11
EPD_RST/1.5D: J1.10
GDR: J1.2, Q3.1 (G), R2_EP_DR.2
GND: C1-EP-DR.1, C27.1, C29.1, C30.1, C31.1, C32.1, C34.1, C42.2, C43.1, D3.2 (GND), D4.1 (K), EPD_C1.1, EPD_C2.1, EPD_C5.1, EPD_C6.1, EPD_C7.1, EPD_C8.1, EPD_C9.1, EPD_C10.1, EPD_C11.1, EPD_C12.1, IC2.B1 (IN/TRIG), IC2.B3 (GND), J1.8, J1.17, J1.MP1, J1.MP2, J4.A1_B12 (GND), J4.A12_B1 (GND), J4.SH1 (SHIELD), J4.SH2 (SHIELD), J4.SH3 (SHIELD), J4.SH4 (SHIELD), R1_USB.1, R2_EP_DR.1, R2_USB.2, R_TYPE_SEL.1, SJ1.1, SW_DN.1, SW_ENT.1, SW_UP.1, TP_BAT_GND.TP, U3.1 (CTG), U3.4 (GND), U3.6 (QSTRT), U3.9 (EP); also elsewhere on the board
HAPTIC_EN/1.4C: IC2.A1 (EN)
MOSI/1.5B: J1.14
unnamed: EPD_C12.2, J1.24
unnamed: C32.2, IC2.A2 (REG)
unnamed: R1_EP_DR.1, R_TYPE_SEL.2, SJ1.2
unnamed: EPD_C10.2, J1.22
unnamed: EPD_C8.2, J1.20
unnamed: EPD_C7.2, J1.19
unnamed: EPD_C6.2, J1.18
unnamed: C2-EP-DR.1, D5.2 (A), L5.1, Q3.3 (D)
unnamed: C2-EP-DR.2, D2.1 (K), D4.2 (A)
unnamed: J4.B5 (CC2), R2_USB.1
unnamed: EPD_C2.2, J1.4
unnamed: EPD_C1.2, J1.5
unnamed: J4.A5 (CC1), R1_USB.2
OUT+: IC2.A3 (OUT+), TP_OP.TP
OUT-: IC2.C3 (OUT-), TP_ON.TP
P0.13/1.5D: C30.2, R5.1, SW_UP.2
P0.14/1.5D: C31.2, R8.1, SW_ENT.2
P1.01/1.6C: Q1.1 (G), R_PWR_EPD.1
P1.02/1.6C: C29.2, R7.1, SW_DN.2
PREVGH: D5.1 (K), EPD_C9.2, J1.21
PREVGL: D2.2 (A), EPD_C11.2, J1.23
RESE: J1.3, Q3.2 (S), R1_EP_DR.2
SCK/1.5B: J1.13
SCL/1.4C: IC2.C1 (SCL), U3.7 (SCL)
SDA/1.4C: IC2.B2 (SDA), U3.8 (SDA)
VBAT/1.2A: C27.2, TP_VBAT.TP, U3.2 (CELL), U3.3 (VDD)
VBUS/1.5D: C42.1, C43.2, D3.5 (VBUS), J4.A4_B9 (VBUS), J4.A9_B4 (VBUS)

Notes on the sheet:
E-Paper Display Connector
E-Paper Drive Circuit
Haptic Driver
Fuel Gauge
Buttons
USB C Connector & ESD Protection
DMG2305UX-7

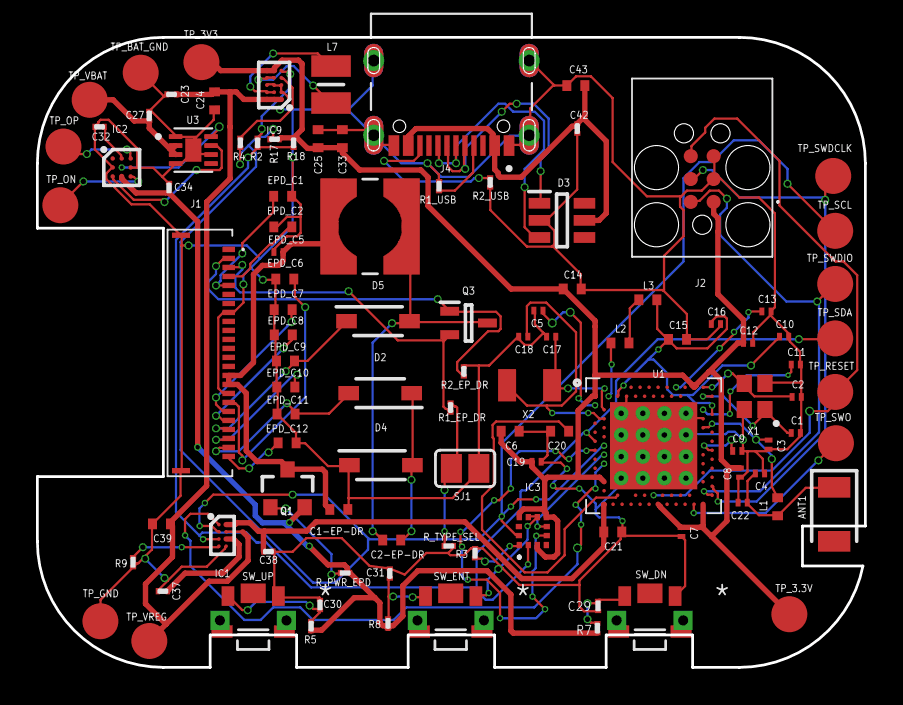
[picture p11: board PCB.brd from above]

Board: 2 copper layers, 46.0 x 35.0 mm, 105 parts (0 on the bottom side), 65 nets.

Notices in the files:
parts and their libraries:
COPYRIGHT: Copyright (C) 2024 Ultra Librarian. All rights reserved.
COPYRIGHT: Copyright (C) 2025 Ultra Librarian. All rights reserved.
